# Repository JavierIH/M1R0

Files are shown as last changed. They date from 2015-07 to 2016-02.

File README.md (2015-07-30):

<!--- Replace first line with:  [RoboWok](http://diwo.bq.com/robowok/) --->
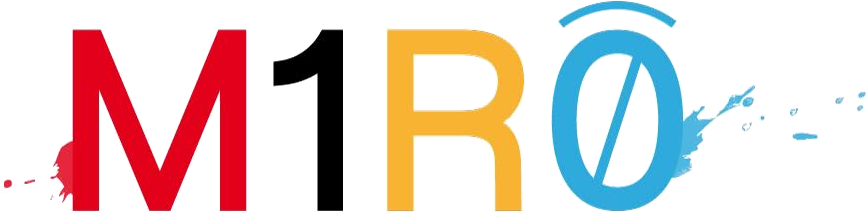
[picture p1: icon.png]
M1R0

--------------------------------------------------------------
--------------------------------------------------------------

A 3D-printable SCARA robot remotely controllable from an Android app.

Attributions
--------------------------------------------------------------
 - [Javier Isabel](https://github.com/JavierIH)
  - Mechanical design

 - [Alvaro Ferrán](https://github.com/alvaroferran)
  - Programming

 - [Alberto Arribas](http://www.albertoarribasart.com/)
  - Artistic design

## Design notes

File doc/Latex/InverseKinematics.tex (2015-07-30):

\documentclass[11pt]{article}

\usepackage{graphicx}
\usepackage{mathtools}
\usepackage{listings}
\usepackage{color}
\definecolor{dkgreen}{rgb}{0,0.6,0}
\definecolor{gray}{rgb}{0.5,0.5,0.5}
\definecolor{mauve}{rgb}{0.58,0,0.82}
\lstset{
  language=Java,
  aboveskip=1mm,
  belowskip=1mm,
  showstringspaces=false,
  columns=flexible,
  basicstyle={\small\ttfamily},
  numbers=none,
  numberstyle=\tiny\color{gray},
  keywordstyle=\color{blue},
  commentstyle=\color{dkgreen},
  stringstyle=\color{mauve},
  breaklines=true,
  breakatwhitespace=true,
  tabsize=3
}

\begin{document}
\thispagestyle{empty}

\begin{center}

 \textsc{\Huge Inverse Kinematics}\\

\vspace{-3.5cm} \hspace{-8.5cm}{
\begin{minipage}[]{\linewidth}% to keep image and caption on one page
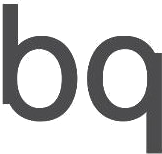
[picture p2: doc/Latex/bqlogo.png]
\center 
\end{minipage}
\hspace{5.5cm}Alvaro Ferr\'an
}

\end{center}

\vspace{2cm} 
\bigskip \flushleft

This document's purpose is to explain how to find the arm's angles when given a position for the end-effector, calculating them geometrically.\\

\begin{minipage}[]{\linewidth}% to keep image and caption on one page
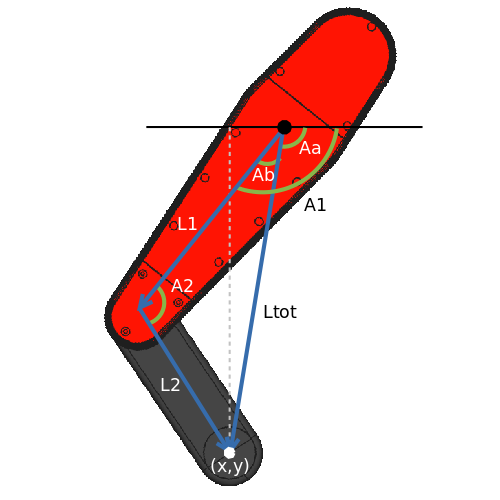
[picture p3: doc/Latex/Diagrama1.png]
\center 
\end{minipage}
\\[0.5cm]
In order to get to position (x,y) we need to find the angles A1 and A2 to which each motor has to move. \\We will start by dividing A1 into two smaller angles: Aa and Ab.
We calculate Aa using the Pythagorean Theorem:

\center $Ltot=\sqrt{x^2+y^2}$
\center $Aa=Acos(\dfrac{x}{Ltot})$

\bigskip 
\flushleft
In order to find Ab, we will use the Law of Cosines:

\center $L2^2=Ltot^2+L1^2-2\cdot Ltot\cdot L1\cdot cos(Ab)$
\center $\rightarrow Ab= Acos(\dfrac{Ltot^2+L1^2-L2^2}{2\cdot Ltot\cdot L1} )$

\flushleft
\bigskip
Thus, 
\center $A1=Aa+Ab$

\newpage 
\thispagestyle{empty}
\flushleft
To find A2 we simply follow the Law of Cosines once more:

\center $Ltot^2=L2^2+L1^2-2\cdot L2\cdot L1\cdot cos(A2)$
\center $\rightarrow A2= Acos(\dfrac{L2^2+L1^2-Ltot^2}{2\cdot L2\cdot L1} )$

\vspace{2.5cm}
\begin{minipage}{\linewidth}%to ensure it stays in the same page

Finally, we implement this algorithm in Java for our Android app:
	\begin{lstlisting}	
 
double[] inverseKinematics(double x, double y) {
	double[] a={0,0};

	double L1=300;
	double L2=200;

	double Ltot=Math.sqrt( Math.pow(x,2) + Math.pow(y,2) );
	double Aa= Math.acos(x/Ltot);
	double Ab= Math.acos( ( Math.pow(Ltot,2) + Math.pow(L1,2) - Math.pow(L2,2) ) / (2*Ltot*L1) );
	double A1=Aa+Ab;
	double A2= Math.acos((Math.pow(L2, 2) + Math.pow(L1, 2) - Math.pow(Ltot, 2)) / (2 * L2 * L1));

	a[0]=A1;
	a[1]=A2;

	return a;
}

\end{lstlisting}
\bigskip
Which may then be called:
\begin{lstlisting}	
double[] angles=inverseKinematics(x,y);
\end{lstlisting}
\end{minipage}

\end{document}

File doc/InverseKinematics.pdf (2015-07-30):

## Inverse Kinematics

Alvaro Ferr´an

This document’s purpose is to explain how to find the arm’s angles when given a position for the end-effector, calculating them geometrically.

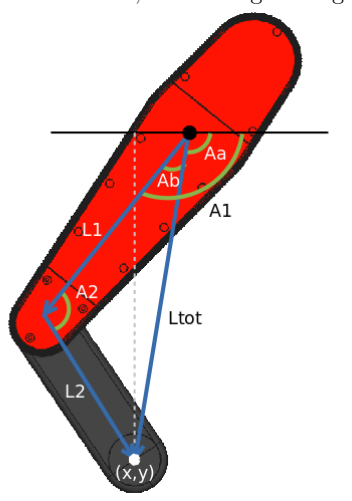
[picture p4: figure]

In order to get to position (x,y) we need to find the angles A1 and A2 to which each motor has to move.
We will start by dividing A1 into two smaller angles: Aa and Ab. We calculate Aa using the Pythagorean Theorem:

Ltot =

p
x

2 + y

2

Aa = Acos(

x
Ltot

)

In order to find Ab, we will use the Law of Cosines:

L2

2 = Ltot² + L1

2 − 2 · Ltot · L1 · cos(Ab)

→ Ab = Acos(

Ltot² + L1

2 − L2

2
2 · Ltot · L1

)

Thus,

A1 = Aa + Ab

To find A2 we simply follow the Law of Cosines once more:

Ltot² = L2

2 + L1

2 − 2 · L2 · L1 · cos(A2)

→ A2 = Acos(

L2

2 + L1

2 − Ltot²
2 · L2 · L1

)

Finally, we implement this algorithm in Java for our Android app:

double[] inverseKinematics(double x, double y) {
double[] a={0,0};

double L1=300;
double L2=200;

double Ltot=Math.sqrt( Math.pow(x,2) + Math.pow(y,2) ); double Aa= Math.acos(x/Ltot);
double Ab= Math.acos( ( Math.pow(Ltot,2) + Math.pow(L1,2) -Math.pow(L2,2) ) / (2*Ltot*L1) );
double A1=Aa+Ab;
double A2= Math.acos((Math.pow(L2, 2) + Math.pow(L1, 2) -Math.pow(Ltot, 2)) / (2 * L2 * L1));

a[0]=A1;
a[1]=A2;

return a;
}

Which may then be called:

double[] angles=inverseKinematics(x,y);

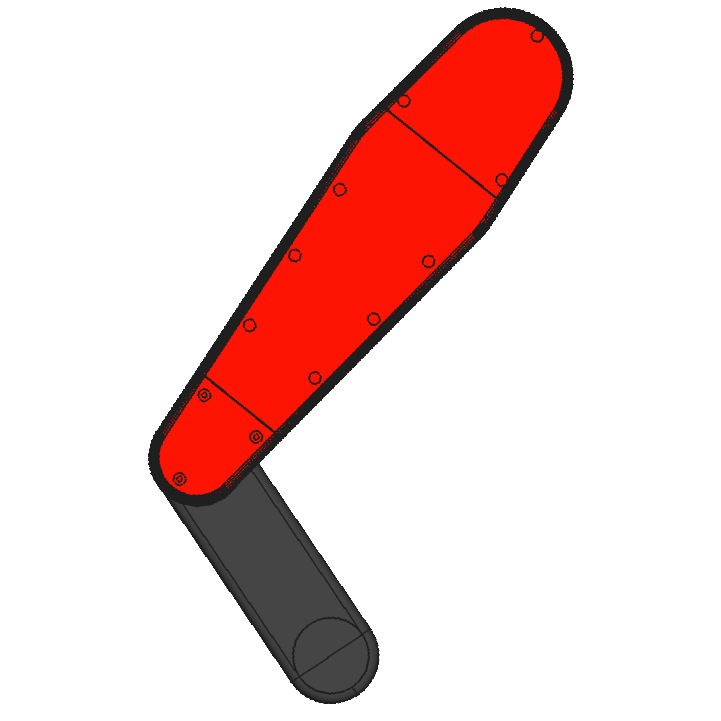
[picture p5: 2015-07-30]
doc/Latex/Captura de pantalla de 2015-07-30 09:31:01.png

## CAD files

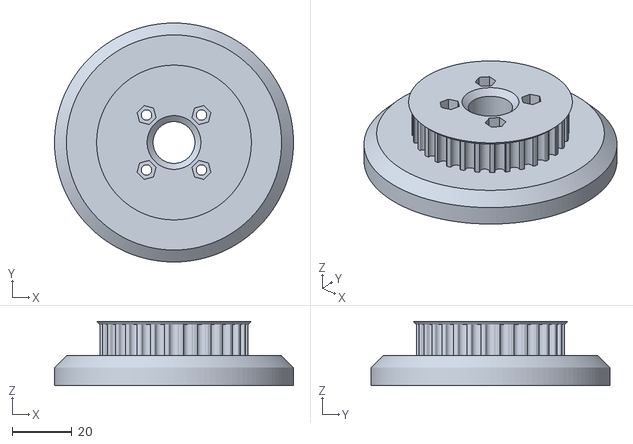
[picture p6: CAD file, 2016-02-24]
parts/stl/mainGear.stl
80.0 x 80.0 x 21.5

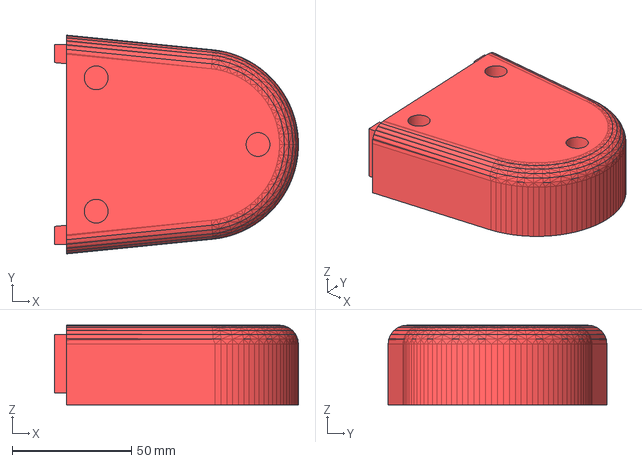
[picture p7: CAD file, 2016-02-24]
parts/step/bodyB1.step
102.5 x 91.9 x 33.5 mm

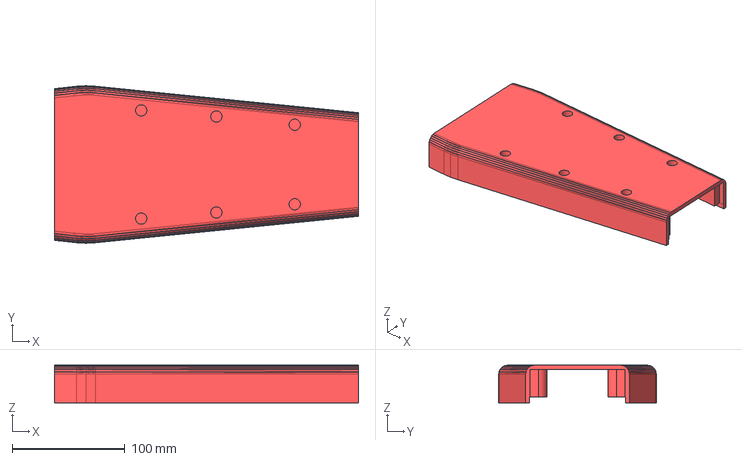
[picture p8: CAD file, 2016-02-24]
parts/step/bodyB2.step
270.0 x 140.0 x 33.5 mm

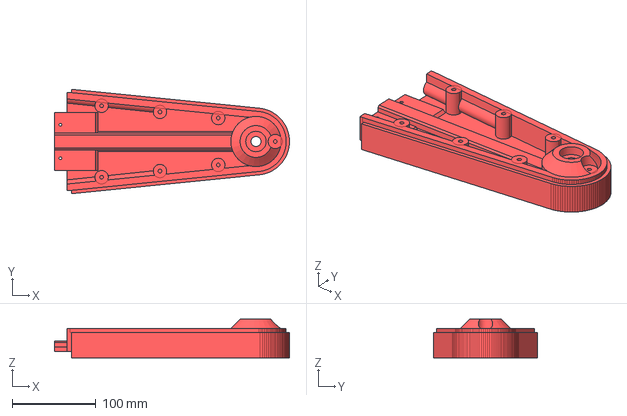
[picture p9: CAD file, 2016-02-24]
parts/step/bodyA1.step
280.5 x 124.7 x 46.0 mm

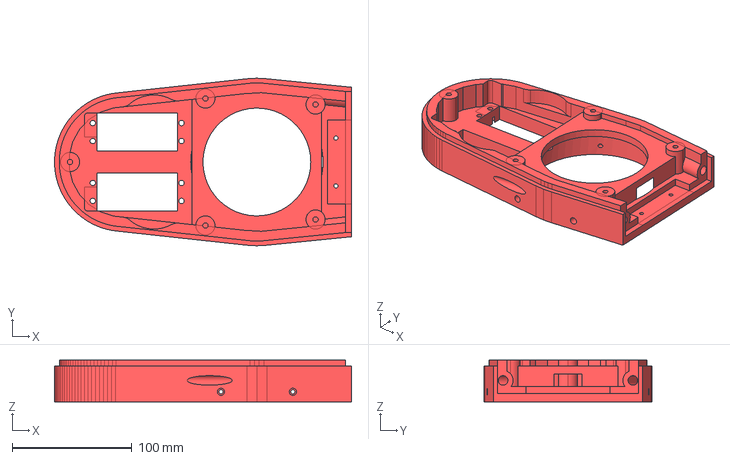
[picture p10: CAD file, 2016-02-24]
parts/step/bodyA2.step
248.0 x 140.0 x 35.0 mm

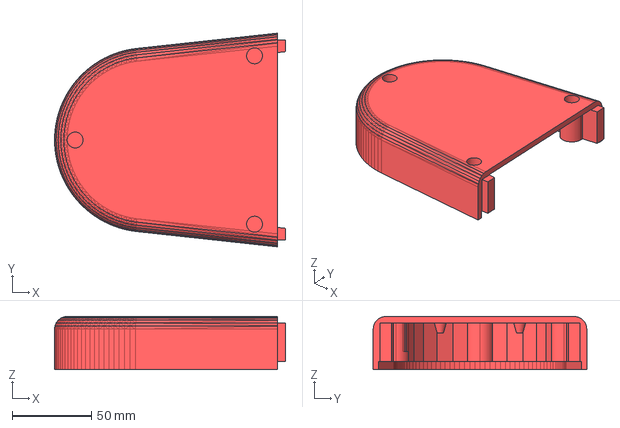
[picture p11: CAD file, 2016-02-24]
parts/step/bodyB3.step
145.5 x 134.6 x 33.5 mm

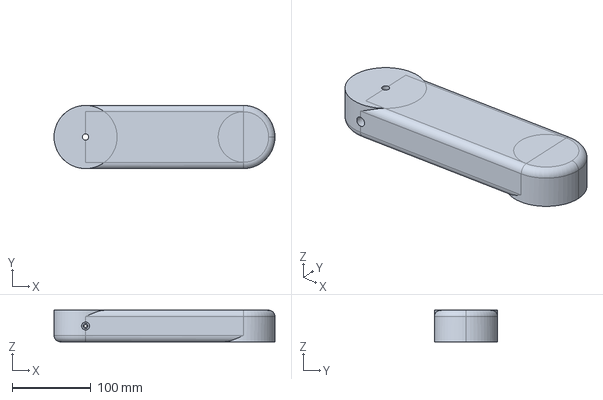
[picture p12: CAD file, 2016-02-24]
parts/step/bodyC.step
280.0 x 80.0 x 40.0 mm

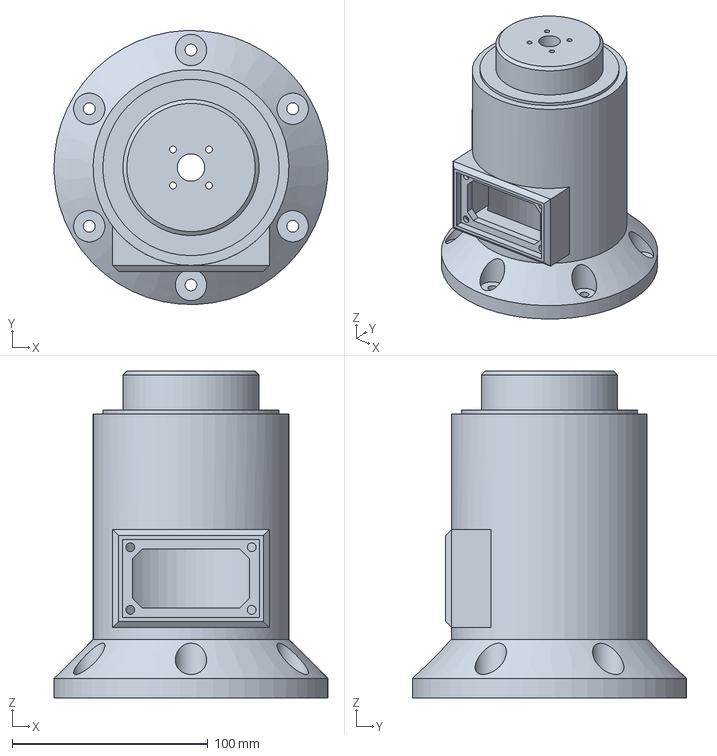
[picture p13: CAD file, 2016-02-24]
parts/step/base.step
139.9 x 139.9 x 167.0 mm

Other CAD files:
parts/stl/base.stl
parts/stl/bodyA1.stl
parts/stl/bodyA2.stl
parts/stl/bodyB1.stl
parts/stl/bodyB2.stl
parts/stl/bodyB3.stl
parts/stl/bodyC.stl

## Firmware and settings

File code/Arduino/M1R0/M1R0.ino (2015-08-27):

#include <Zowi.h>
#include <Servo.h>
#include <Oscillator.h>
#include <EEPROM.h>

int pinLinear1=2, pinLinear2=3, pinBlack=4, pinYellow=5, pinWhite=6,  pinLink1=8, pinLink2=9, pinNeedle=10;
bool newInfoReceived=false;

int memBlack=50, memYellow=60, memWhite=70;

Zowi zowi;
int pos[] = {0, 140, 0,0};




void setup(){
	Serial.begin(19200);
	Serial.flush();

	zowi.init(pinLink1, pinLink2, 12, 11, 0); //4 servos + bool 0 = doesn't read from eeprom
	zowi.setTrims(0,0,0,0); //adjust center for servo
	zowi.moveServos(0, pos);

	pinMode(pinLinear1, OUTPUT);
	pinMode(pinLinear2, OUTPUT);

	//Start with needle up
	Servo myServo;
	myServo.attach(pinNeedle);
	myServo.write(90);
	delay(500);
	myServo.detach();

	}




String readString(){
	String inString ="";
	char inChar;
	while(Serial.available()>0){
		inChar =(char) Serial.read();
		inString+=inChar;
		delay(1);
	}
	newInfoReceived=true;
	return inString;
}


void recharge(int i){
	static Servo myServo;
	int pin[3]={pinBlack,pinYellow, pinWhite};
	int mem[3]={memBlack,memYellow, memWhite};
	int posInit=50;

	myServo.attach(pin[i]);
	myServo.write(posInit);
	EEPROM.write(mem[i], posInit);
	delay(1000);
	myServo.detach();
	//Serial.println(i);
}

void linearActuator(){
	int ms=24000;
	digitalWrite(pinLinear1, HIGH);
	digitalWrite(pinLinear2, LOW);
	setCoordinates(0,140,5000);
	delay(ms);
	digitalWrite(pinLinear1, LOW);
	digitalWrite(pinLinear2, HIGH);
	delay(24000);
	digitalWrite(pinLinear1, LOW);
	digitalWrite(pinLinear2, LOW);
}





bool setCoordinates(int a1, int a2, int moveTime){
	pos[0]=a1;
	pos[1]=a2;
	zowi.moveServos(moveTime, pos); 
	return true;
}




void useTool(int tool, int state){
	static Servo myServo;
	myServo.attach(tool);

	//static int posInit=50;
	int posFinal=134;//140
	int steps=14;//5	
	// (134-50)/14=6 times each color
	int ms=1000;
	
	//static int positions[3]={posInit,posInit,posInit};
	static int positions[3]={EEPROM.read(memBlack),EEPROM.read(memYellow),EEPROM.read(memWhite)};

	if(tool==pinBlack){
		if(positions[0]<posFinal) {
	 		positions[0]=positions[0]+steps; //increment position of syringe
	 		myServo.write(positions[0]);
	 		EEPROM.write(memBlack, positions[0]);
		 	}
	}
	else if (tool==pinYellow){
		if(positions[1]<posFinal) {
	 		positions[1]=positions[1]+steps; 
	 		myServo.write(positions[1]); 
	 		EEPROM.write(memYellow, positions[1]);		
		 	}
	}
	else if (tool==pinWhite){
		if(positions[2]<posFinal) {
	 		positions[2]=positions[2]+steps; 
	 		myServo.write(positions[2]); 
	 		EEPROM.write(memWhite, positions[2]);		
		 	}
	}
	else if (tool==pinNeedle){
		if (state==0 ){
			myServo.write(5); //needle down
			ms=200;
		}
		else{
			myServo.write(90); //needle up
			ms=500;
		}
	}

	delay(ms);
	myServo.detach();
}




void think(String msg){
	if (msg=="linearAct")	{
		linearActuator();	
	}
	else if(msg=="up"){
		useTool(pinNeedle,1);
		delay(10);
	}
	else if(msg.substring(0,8)=="recharge"){
		recharge( msg.substring(8).toInt() );
	}
	else if (msg!=""){
		int commaIndex = msg.indexOf(',');
		int commaIndex2 = msg.indexOf(',', commaIndex+1);
		int commaIndex3 = msg.indexOf(',', commaIndex2+1);

		int A1 = msg.substring(0, commaIndex).toInt();
		int A2 = msg.substring(commaIndex+1, commaIndex2).toInt();
		int moveTime = msg.substring(commaIndex2+1, commaIndex3).toInt();
		int scaraOption=msg.substring(commaIndex3+1).toInt();
		
		int finishedMoving=false;

		finishedMoving=setCoordinates(A1,A2,moveTime);
		if(A1==0 && A2==140) Serial.end(); //end comms with scara in starting position
		
		int pinTool;
		switch (scaraOption) {
			case 1:
				pinTool=pinBlack;
				break;
			case 2:
				pinTool=pinYellow;
				break;
			case 3:
				pinTool=pinWhite;
				break;
			case 4:
				pinTool=pinNeedle;
				break;
			default:
				pinTool=0;
		}
		
		if (pinTool!=0)
			if(finishedMoving==true) useTool(pinTool,0);
	}
}




void loop(){
	String incoming;
	if(Serial.available()) incoming=readString();
	if (newInfoReceived==true){
		think(incoming);
		newInfoReceived=false;
	}
}

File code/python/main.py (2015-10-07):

import os
import sys
sys.path.append(os.path.dirname(os.path.abspath(__file__)))

import smbus
import pygame
import time
from hardware.pca9865.pca9865 import ServoController
from control.kinematics.kinematics import Kinematics

pygame.init()
clock = pygame.time.Clock()
pygame.joystick.init()
joystick = pygame.joystick.Joystick(0)
joystick.init()

ik = Kinematics()

bus = smbus.SMBus(1)

control = ServoController(bus, 0x40)
control.addServo(0,0)
control.addServo(1,0)

position_x = 0
position_y = 0

gain = 10
speed = 1

limit_max_y = 250
limit_min_y = -250
limit_max_x = 400
limit_min_x = 150

control.move(0, 0)
control.move(1, 0)

position_x = (limit_max_x + limit_min_x)/2
position_y = (limit_max_y + limit_min_y)/2


while True:
    for event in pygame.event.get():
        pass
    
#    axes = joystick.get_numaxes()
#    for i in range(axes):
#        axis = joystick.get_axis(i)

#    buttons = joystick.get_numbuttons()
#    for i in range(buttons):
#        button = joystick.get_button(i)
            
#    hats = joystick.get_numhats()
#    for i in range(hats):
#        hat = joystick.get_hat(i)

    
    x = joystick.get_axis(0)
    y = joystick.get_axis(1)
    speed = (-joystick.get_axis(3)+1)/2


#    print '\n'*100, x, '\n', y

    if joystick.get_button(0):
        if not ((position_x > limit_max_x and x > 0) or (position_x < limit_min_x and x < 0)):
            position_x += x*speed*gain
        if not ((position_y > limit_max_y and y > 0) or (position_y < limit_min_y and y < 0)):
            position_y += y*speed*gain

    if joystick.get_button(4):
        position_x = (limit_max_x + limit_min_x)/2
        position_y = (limit_max_y + limit_min_y)/2

    print '\n'*100
    print 'Posicion en X: ', position_x
    print 'Posicion en Y: ', position_y
    print 'Velocidad: ', speed

    joints = ik.getTargetJoints([control.getPosition(0), control.getPosition(1)],[position_x, position_y])

    print 'Angulo alpha: ', joints[0] 
    print 'Angulo beta: ', joints[1] 

    control.move(0, joints[0])
    control.move(1, joints[1])

    clock.tick(50)

    
pygame.quit()

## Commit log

2015-07-31 Code adjustments for syringes
2015-08-19 Syringe refill option added
2015-10-07 Added servo controller
2015-10-07 working prototype python code
2016-02-24 generated step files
    [base.step, bodyA1.step, bodyA2.step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]
2016-02-24 stl printable files
    [base.stl, bodyA1.stl, bodyA2.stl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]
